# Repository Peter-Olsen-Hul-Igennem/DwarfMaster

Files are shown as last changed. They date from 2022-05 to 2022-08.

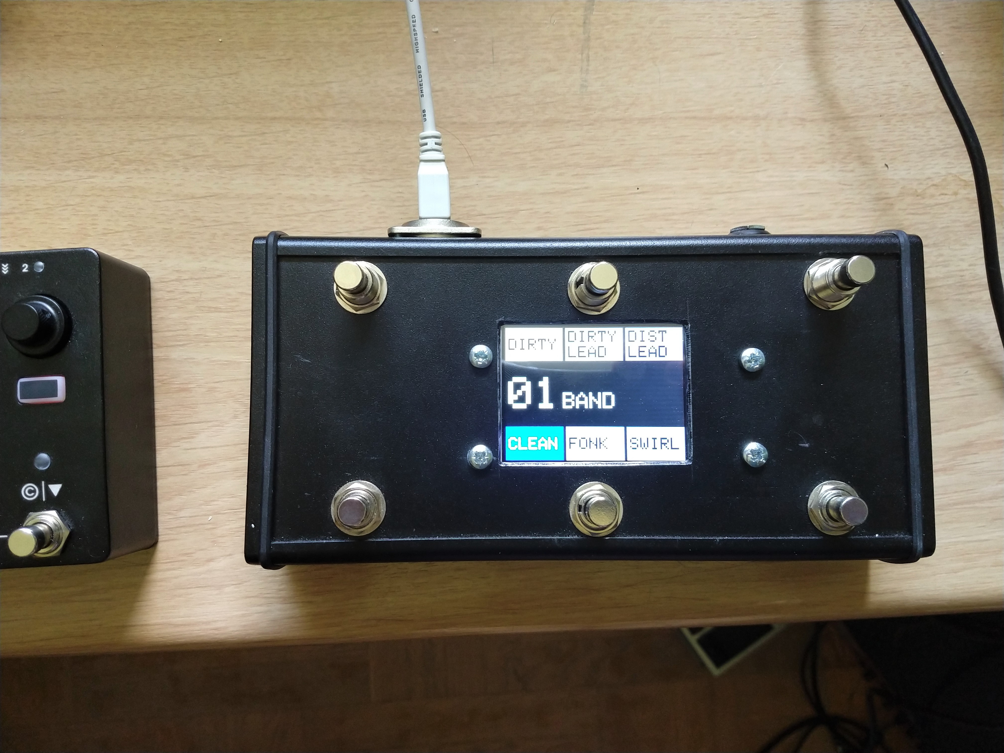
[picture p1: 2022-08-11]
misc/DwarfMaster.jpg

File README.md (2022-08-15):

# DwarfMaster
11-08-2022

Midi controller for Mod Devices Dwarf

As no commercially avalible midi foot controller meet all of my requirements I have decided to build one myself.

The controller is build with a Teensy 4.1 as the "brain". The Teensy is fitted with a MicroSD card for storrage of data.
The controller has a small touch screen that shows selected bank, patch and other relevant info. The "programming" of the controller is also done with the touch screen.

This repository will hold source files and other documentation related to the build.
This is not ment to be a community project as the controller is tailored to my specific needs, but all code is avalible to anyone doing a similar project.
This is my first project using the Arduino/Teensy platform, and the code shows that I'm learning as I go - so quite a few "hacks" and inconsistencies can be found.

The code is developed using VisualTeensy and Visual Studio Code.
These libraries are used: ArduinoJson 6.19.4, Adafruit_BusIO 1.11.5, Adafruit_TouchScreen 1.1.3, Adafruit_GFX_Library 1.10.14, MCUFRIEND_kbv 2.9.9, EEPROM 2.0, SD 2.0.0, SdFat 2.1.0, SPI 1.0, Wire 1.0, MIDI Library 5.0.2

The controller has 6 footswitches that can be set up as a "preset" of "toggle" button. The preset footswitches are mutually exclusive. Pressing a footswitch can trigger up to 16 PC and 16 CC messages being send. Preset footswitches can be configured to have a secondary press function that can send another 16 PC and 16 CC massages.

The six footswitches constitute a Bank. There are 100 banks. A PC message can be send on changing to a new bank (to load a pedalboard in the Dwarf). Bank up and down is done with pressing footswitch 1+2 (down) and 2+3 (up).

All configuration of footswitches and banks (names, pc's, cc's, preset/toggle, 2. function) is done via the touchscreen with footswitch 3 as "ok" button and footswitch 1 as "cancel/exit".
There is utility functions for copying banks and footswitches as well as sending a single CC (for midi-learn purpose).

All midi messages are send on both the USB port as well as a standard 5 pin midi connector.

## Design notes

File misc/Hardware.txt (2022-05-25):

Teensy 4.1	: https://www.conradelektronik.dk/p/pjrc-mikrocontroller-teensy-41-2269230
Display		: https://www.conradelektronik.dk/p/tru-components-touchscreen-monitor-71-cm-28-tommer-320-x-240-pixel-inkl-touchpen-2144984
Buttons		: https://www.banzaimusic.com/Momentary-Soft-Touch-SPST-NO-Long.html

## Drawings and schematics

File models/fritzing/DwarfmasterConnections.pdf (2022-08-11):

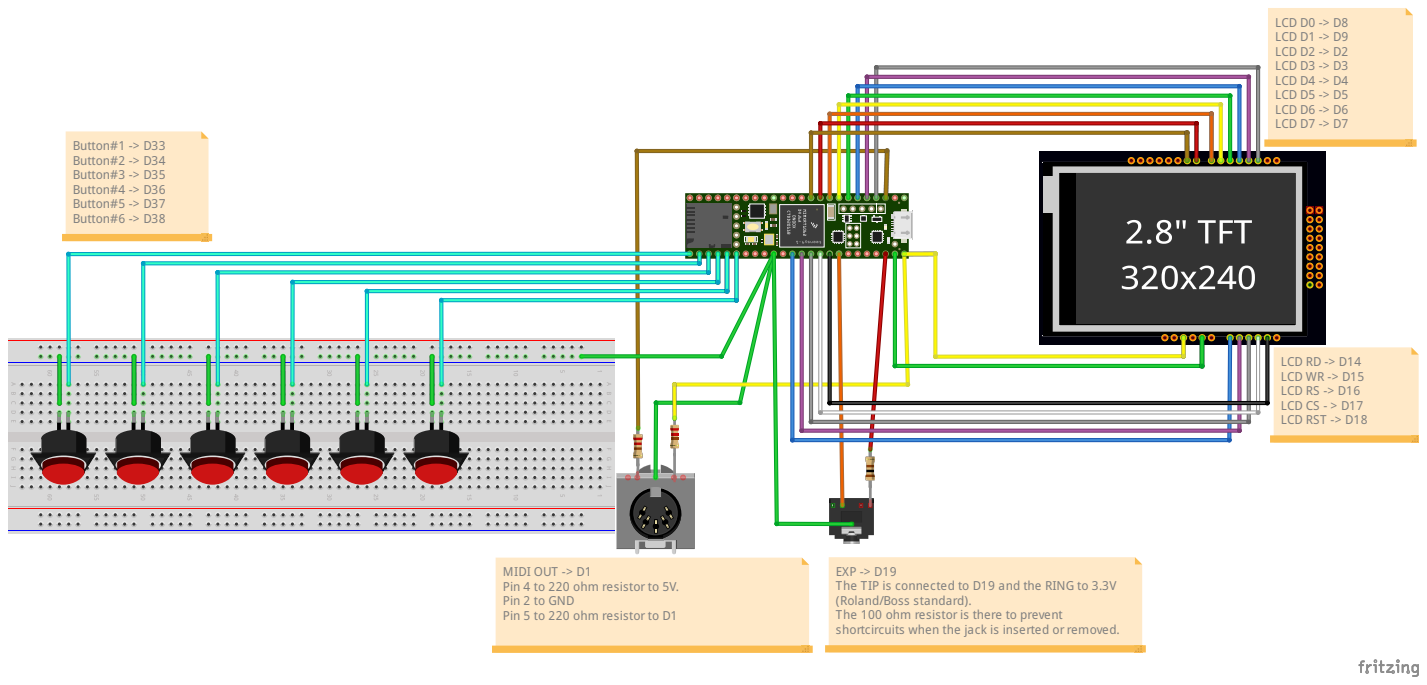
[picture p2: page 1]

MIDI OUT -> D1
Pin 4 to 220 ohm resistorto 5V.
Pin 2 to GND
Pin 5 to 220 ohm resistorto D1

EXP -> D19
The TIP is connected to D19 and the RING to 3.3V
(Roland/Boss standard).
The 100 ohm resistoris there to prevent
shortcircuits when the jack is inserted orremoved.

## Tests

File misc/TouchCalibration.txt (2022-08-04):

I'm using the MCUFREIND_kbv library to read touch data from the screen. Every touch screen is different so some screen specific values needs to be set up.
The values are meassured/retreived with the TouchScreen_Calibr_native.ino sketch that comes with MCUFREIND_kbv

I needed to make a small change in the sketch so the touch was read on the correct pins (found with the diagnose_Touchpins sketch):
int XP=8, XM=A2, YP=A3, YM=9;

These are the values for my screen:

const int TS_LEFT=937,TS_RT=99,TS_TOP=72,TS_BOT=915;

PORTRAIT CALIBRATION     240 x 320
x = map(p.x, LEFT=937, RT=99, 0, 240)
y = map(p.y, TOP=72, BOT=915, 0, 320)

LANDSCAPE CALIBRATION    320 x 240
x = map(p.y, LEFT=72, RT=915, 0, 320)
y = map(p.x, TOP=99, BOT=937, 0, 240)

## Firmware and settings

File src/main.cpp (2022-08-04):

#include "ButtonState.h"
#include "ExpressionHandler.h"
#include "GlobalConst.h"
#include "MidiCtrlData.h"
#include "MidiTransmitter.h"
#include "Screen.h"
#include "Touch.h"
#include <Arduino.h>
#include <EEPROM.h>

enum CtrlState { PLAY,
                 PLAY_BANK_UP,
                 PLAY_BANK_DOWN,
                 EDIT_BANK,
                 EDIT_BTN };
CtrlState ctrlState = PLAY;

enum BtnPushState { VERY_FIRST_BTN_PUSH,
                    FIRST_BTN_PUSH,
                    SECOND_BTN_PUSH };

enum PcCcEnum { PC_1_8,
                PC_9_16,
                CC_1_8,
                CC_9_16 };

const uint16_t DATA_STATE_EEPROM_ADR = 0;
const uint8_t EXP_PIN                = 19;

void setup();
void loop();

void playMode();
void bankChange(bool up);
void drawPlayScreen();
void drawPlayBtns(const bool overrideSelected, const bool invertSelected = false);
void drawPlayBank(const int bnkNbr, const bool inverted);
void sendButtonMidi(Button button, BtnPushState btnState);

void editMode(uint8_t editBtnNbr);
void doEditUtility();
bool doEditBank();
bool doEditBtn(uint8_t btnNbr);
bool doPcCcEdit(Button* button, uint8_t btnNbr, PcCcEnum pcCc);
bool doPcCcDetailsEdit(Button* button, uint8_t btnNbr, uint8_t pcCcNbr, PcCcEnum pcCc);

void loadDataStateInfo();
void saveDataStateInfo();
void bankNumToChar(uint8_t num, char* buf);
void initHousekeepingVariables();
void togglePushBtnState(uint8_t btnNbr);

void setMainLabelAttributes();
void setUtilityLabelAttributes();
void setBankLabelAttributes();
void setButtonLabelAttributes(const Button* button);
void setPc1LabelAttributes(const Button* button);
void setPc2LabelAttributes(const Button* button);
void setCc1LabelAttributes(const Button* button);
void setCc2LabelAttributes(const Button* button);
void setPcDetailLabelAttributes(const PcMsg* msg);
void setCcDetailLabelAttributes(const CcMsg* msg);

EditLabelAttributes editLabelAttrib[9];

Screen screen; // TODO pointer
MidiCtrlData* mcd;
Bank* bank;
ButtonState* btnState = btnState->getInstance();
MidiTransmitter* midiTransmitter;
ExpressionHandler* expressionHandler;

struct DataState
{
    uint8_t bnk;
    uint8_t btn;
    BtnPushState btnPushState = VERY_FIRST_BTN_PUSH;
    uint16_t expMin;
    uint16_t expMax;
};
DataState dataState;

bool toggleStates[NUMBER_OF_BUTTONS]; // Keeping track of the states of the toggle switches (buttons not set up to be patches). True is ON.

void setup()
{
    Serial.begin(9600);
    //    delay(1000);

    loadDataStateInfo();
    mcd  = new MidiCtrlData();
    bank = mcd->getBank(dataState.bnk);

    expressionHandler = new ExpressionHandler(EXP_PIN, dataState.expMin, dataState.expMax);
    midiTransmitter   = new MidiTransmitter(expressionHandler);

    initHousekeepingVariables();

    screen.showWaitScreen();
    screen.waitForButtonReleased();

    sendButtonMidi(bank->buttons[dataState.btn - 1], dataState.btnPushState);

    drawPlayScreen();
}

void loop()
{
    uint8_t playBtnPressed = 0;

    // switch that sets up state
    switch (ctrlState)
    {
        case PLAY:
            if (btnState->isBankUpState())
            {
                ctrlState = PLAY_BANK_UP;
            }
            else if (btnState->isBankDownState())
            {
                ctrlState = PLAY_BANK_DOWN;
            }
            else if (screen.playBankPressed())
            {
                ctrlState = EDIT_BANK;
            }
            else
            {
                playBtnPressed = screen.playBtnPressed();
                if (playBtnPressed > 0)
                {
                    ctrlState = EDIT_BTN;
                }
            }

            break;

        case PLAY_BANK_UP:
        case PLAY_BANK_DOWN:
            ctrlState = PLAY;
            break;

        case EDIT_BANK:
        case EDIT_BTN:
            ctrlState = PLAY;
            break;
    }

    // switch that reacts to a given state
    switch (ctrlState)
    {
        case PLAY:
            playMode();
            break;
        case PLAY_BANK_UP:
            bankChange(true);
            break;
        case PLAY_BANK_DOWN:
            bankChange(false);
            break;
        case EDIT_BANK:
            editMode(0);
            break;
        case EDIT_BTN:
            editMode(playBtnPressed);
            break;
    }

    while (usbMIDI.read())
    {
        // ignore incoming messages
    }
}

void playMode()
{
    byte btnNbr = btnState->getSingleButtonPressed();
    if (btnNbr > 0) // A footswitch was pushed
    {
        if (bank->buttons[btnNbr - 1].isPatch)
        {
            if (btnNbr == dataState.btn)
                togglePushBtnState(btnNbr - 1);
            else
                dataState.btnPushState = VERY_FIRST_BTN_PUSH;
            
            sendButtonMidi(bank->buttons[btnNbr - 1], dataState.btnPushState);
            dataState.btn = btnNbr;
            saveDataStateInfo();
        }
        else
        {
            toggleStates[btnNbr - 1] = !toggleStates[btnNbr - 1];
            if (toggleStates[btnNbr - 1])
                sendButtonMidi(bank->buttons[btnNbr - 1], FIRST_BTN_PUSH);
            else
                sendButtonMidi(bank->buttons[btnNbr - 1], SECOND_BTN_PUSH);
        }

        drawPlayBtns(false);
    }
    else
    {
        for (uint8_t i = 0; i < NUMBER_OF_BUTTONS; i++)
        {
            if (!bank->buttons[i].isLatching && btnState->isButtonJustReleased(i + 1))
            {
                if (bank->buttons[i].isPatch)
                    togglePushBtnState(i);
                else
                    toggleStates[i] = !toggleStates[i];
                
                sendButtonMidi(bank->buttons[i], SECOND_BTN_PUSH);
                drawPlayBtns(false);
            }
        }
    }

    // Send Expressionpedal midi
    midiTransmitter->sendExpressionMessages(bank, toggleStates, dataState.btn);
}

void bankChange(bool up)
{
    unsigned long prevMillis = millis();
    unsigned long curMillis;
    const unsigned long period = 500;
    int btnNbr1;
    int btnNbr2;
    bool bBlink     = false;
    bool first      = true;
    byte tmpBankNbr = dataState.bnk;

    while (true)
    {
        if ((first && up) || btnState->isBankUpState())
        {
            if (tmpBankNbr == NUMBER_OF_BANKS - 1)
                tmpBankNbr = 0;
            else
                tmpBankNbr++;
            bank = mcd->getBank(tmpBankNbr);
        }
        else if ((first && !up) || btnState->isBankDownState())
        {
            if (tmpBankNbr == 0)
                tmpBankNbr = NUMBER_OF_BANKS - 1;
            else
                tmpBankNbr--;
            bank = mcd->getBank(tmpBankNbr);
        }
        first = false;

        curMillis = millis();
        if (curMillis - prevMillis >= period)
        {
            bBlink = !bBlink;
            drawPlayBank(tmpBankNbr, bBlink);
            drawPlayBtns(true);
            prevMillis = curMillis;
        }
        btnNbr1 = btnState->getSingleButtonPressed();
        if (btnNbr1 > 0 && bank->buttons[btnNbr1 - 1].isPatch) // Load selected bank
        {
            midiTransmitter->sendPcMsg(bank->pcMessage, true); // Send Bank Midi

            dataState.bnk          = tmpBankNbr;
            dataState.btn          = btnNbr1;
            dataState.btnPushState = VERY_FIRST_BTN_PUSH;
            saveDataStateInfo();
            initHousekeepingVariables();

            bBlink = true;
            while (true)
            {
                btnNbr2 = btnState->getSingleButtonPressed(true);
                if (btnNbr1 == btnNbr2) // The seledted button (patch) is pressed again.
                {                       // This allows the user to wait until the bank is loaded in the Dwarf, before sending patch related midi messages.
                    break;
                }
                curMillis = millis();
                if (curMillis - prevMillis >= period)
                {
                    bBlink = !bBlink;
                    drawPlayBtns(false, bBlink);
                    prevMillis = curMillis;
                }
                if (usbMIDI.read()) // Recieving any midi data from the Dwarf will signal that the bank is loaded. Tip: The InfamousMindi will send a midi msg on loading! 
                    break;
            }

            sendButtonMidi(bank->buttons[btnNbr1 - 1], dataState.btnPushState);

            drawPlayScreen();

            break;
        }
    }
}

void drawPlayScreen()
{
    screen.blankScreen();
    drawPlayBtns(false);
    drawPlayBank(dataState.bnk, false);
}

void drawPlayBtns(const bool overrideSelected, const bool invertSelected)
{
    byte curPatch    = dataState.btn;
    bool selected    = false;
    bool primaryFunc = true;

    for (byte i = 0; i < NUMBER_OF_BUTTONS; i++)
    {
        primaryFunc = true;
        if (!overrideSelected)
            selected = curPatch == i + 1; // Blue color patch
        if (bank->buttons[i].isPatch)
        {
            if (selected && dataState.btnPushState == SECOND_BTN_PUSH)
                primaryFunc = false; // Red color patch
        }
        else
        {
            if (toggleStates[i] == true)
                primaryFunc = false; // Toggle ON
        }
        screen.drawPlayButton(i + 1, bank->buttons[i].isPatch, selected, primaryFunc, bank->buttons[i].name, invertSelected);
    }
}

void drawPlayBank(const int bnkNbr, const bool inverted)
{
    char bankNumber[3];
    bankNumToChar(bnkNbr, bankNumber);
    screen.drawPlayBank(bankNumber, bank->name, inverted);
}

void sendButtonMidi(Button button, BtnPushState btnState)
{
    for (uint8_t i = 0; i < NUMBER_OF_MIDI_MSG; i++)
    {
        switch (btnState)
        {
            case VERY_FIRST_BTN_PUSH:
                midiTransmitter->sendPcMsg(button.pcMessages[i], true);
                break;

            case FIRST_BTN_PUSH:
                if (button.pcMessages[i].valueOn != button.pcMessages[i].valueOff) // If the On and Off values are the same, the PC is not (re)sent.
                    midiTransmitter->sendPcMsg(button.pcMessages[i], true);
                break;

            case SECOND_BTN_PUSH:
                if (!button.isPatch || button.isSecondPushEnabled)                     // Toggle or secondPushEnabled
                    if (button.pcMessages[i].valueOn != button.pcMessages[i].valueOff) // If the On and Off values are the same, the PC is not (re)sent.
                        midiTransmitter->sendPcMsg(button.pcMessages[i], false);
                break;
        }
    }

    for (uint8_t i = 0; i < NUMBER_OF_MIDI_MSG; i++)
    {
        switch (btnState)
        {
            case VERY_FIRST_BTN_PUSH:
            case FIRST_BTN_PUSH:
                midiTransmitter->sendCcMsg(button.ccMessages[i], true, button.ccMessages[i].useMaxValAsCcNbr);
                break;

            case SECOND_BTN_PUSH:
                if (!button.isPatch || button.isSecondPushEnabled)
                {
                    midiTransmitter->sendCcMsg(button.ccMessages[i], false, button.ccMessages[i].useMaxValAsCcNbr);
                }
                break;
        }
    }
}


/*
 * EDIT functions starts here
 */
void editMode(uint8_t editBtnNbr)
{
    bool dirty = false;
    char label[13];
    bankNumToChar(dataState.bnk, label);
    label[2] = ' ';

    int btn;
    bool loop = true;

    if (editBtnNbr > 0) // A field representing a button on the screen was pressed
    {
        loop  = false;
        dirty = doEditBtn(editBtnNbr);
    }

    while (loop)
    {
        strlcpy(label + 3, bank->name, 13);
        setMainLabelAttributes();
        screen.drawEdit(label, editLabelAttrib);
        screen.waitForButtonReleased();

        btn = screen.getButtonPushed();
        switch (btn)
        {
            case 0: // CALCEL
            case 1: // EXIT
                loop = false;
                break;
            case 2: // BANK
                dirty = doEditBank() || dirty;
                break;
            case 3: // UTILITY
                doEditUtility();
                break;
            case 4: // BTN #4
            case 5: // BTN #5
            case 6: // BTN #6
            {
                dirty = doEditBtn(btn) || dirty;
                break;
            }
            case 7: // BTN #1
            case 8: // BTN #2
            case 9: // BTN #3
            {
                dirty = doEditBtn(btn - 6) || dirty;
                break;
            }
        }
    }

    if (dirty)
        mcd->saveBank(dataState.bnk);

    drawPlayScreen();
    screen.waitForButtonReleased();
}

void doEditUtility()
{
    int btn;
    bool loop = true;

    char label1[16];
    char label2[16];
    char cNewVal[4];
    String label;
    String sVal;
    uint16_t newVal;

    while (loop)
    {
        setUtilityLabelAttributes();
        screen.drawEdit("UTILITY", editLabelAttrib);
        screen.waitForButtonReleased();

        btn = screen.getButtonPushed();
        switch (btn)
        {
            case 0: // CALCEL
            case 1: // EXIT
                loop = false;
                break;
            case 2: // COPY BANK
            {
                label          = String("TO BANK");
                sVal           = String(dataState.btn);
                uint8_t bankTo = screen.getNumKeyboardInputFromUser(&label, &sVal, 2);
                if (bankTo > NUMBER_OF_BANKS)
                {
                    screen.showMessage("INVALID CHOICE");
                    break;
                }

                strlcpy(label2, "   CANCEL ", sizeof(label2));
                strlcpy(label1, "BANK: ", sizeof(label1));
                itoa(dataState.bnk, cNewVal, 10);
                strlcat(label1, cNewVal, sizeof(label1));
                strlcat(label1, "->", sizeof(label1));
                itoa(bankTo, cNewVal, 10);
                strlcat(label1, cNewVal, sizeof(label1));
                if (screen.getBinaryInputFromUser(label1, label2, false))
                {
                    mcd->copyBank(dataState.bnk, bankTo);
                }
                break;
            }

            case 3: // RESET BANK
            {
                strcpy(label1, " RESET BANK");
                strcpy(label2, "   CANCEL");
                if (screen.getBinaryInputFromUser(label1, label2, false))
                {
                    mcd->resetBank(dataState.bnk);
                }
                break;
            }
            case 4: // EXP CALIBRATION
            {
                screen.showMessage("MOVE PEDAL TO THE <MIN> POSITION AND PRESS THE SCREEN");
                dataState.expMin = expressionHandler->readCalibrationValue(false);
                screen.showMessage("MOVE PEDAL TO THE <MAX> POSITION AND PRESS THE SCREEN");
                dataState.expMax = expressionHandler->readCalibrationValue(true);

                char msg[85];
                char val[5];
                strlcpy(msg, "MIN: ", 85);
                itoa(dataState.expMin, val, 10);
                strlcpy(msg + strlen(msg), val, 85);
                strlcpy(msg + strlen(msg), "         MAX: ", 85);
                itoa(dataState.expMax, val, 10);
                strlcpy(msg + strlen(msg), val, 85);
                screen.showMessage(msg);

                saveDataStateInfo();
                break;
            }
            case 5: // COPY BUTTON
            {
                label           = String("BTN FROM");
                sVal            = String(dataState.btn);
                uint8_t btnFrom = screen.getNumKeyboardInputFromUser(&label, &sVal, 1);
                if (btnFrom == 0)
                {
                    screen.showMessage("NO BUTTON CHOSEN");
                    break;
                }
                else if (btnFrom > NUMBER_OF_BUTTONS)
                {
                    screen.showMessage("INVALID CHOICE");
                    break;
                }

                label          = String("TO BANK");
                sVal           = String(dataState.bnk);
                uint8_t bankTo = screen.getNumKeyboardInputFromUser(&label, &sVal, 2);
                // No need to check if bankTo > 99, because getNumKeyboardInputFromUser(&label, &sVal, 2) only allows 2 digits

                label         = String("TO BUTTON");
                sVal          = String(dataState.btn);
                uint8_t btnTo = screen.getNumKeyboardInputFromUser(&label, &sVal, 1);
                if (btnTo == 0)
                {
                    screen.showMessage("NO BUTTON CHOSEN");
                    break;
                }
                else if (btnTo > NUMBER_OF_BUTTONS)
                {
                    screen.showMessage("INVALID CHOICE");
                    break;
                }

                strlcpy(label2, "   CANCEL ", sizeof(label2));
                strlcpy(label1, "BTN:", sizeof(label1));
                itoa(btnFrom, cNewVal, 10);
                strlcat(label1, cNewVal, sizeof(label1));
                strlcat(label1, " > ", sizeof(label1));
                itoa(bankTo, cNewVal, 10);
                strlcat(label1, cNewVal, sizeof(label1));
                strlcat(label1, " ", sizeof(label1));
                itoa(btnTo, cNewVal, 10);
                strlcat(label1, cNewVal, sizeof(label1));
                if (screen.getBinaryInputFromUser(label1, label2, false))
                {
                    mcd->copyButton(dataState.bnk, btnFrom - 1, bankTo, btnTo - 1);
                }
                break;
            }
            case 6: // RESET BUTTON
            {
                label  = String("BTN NBR");
                sVal   = String("0");
                newVal = screen.getNumKeyboardInputFromUser(&label, &sVal, 1);
                if (newVal == 0)
                {
                    screen.showMessage("NO BUTTON CHOSEN");
                    break;
                }
                else if (newVal > NUMBER_OF_BUTTONS)
                {
                    screen.showMessage("INVALID CHOICE");
                    break;
                }

                strlcpy(label2, "   CANCEL", sizeof(label2));
                itoa(newVal, cNewVal, 10);
                strlcpy(label1, "RESET BTN: ", sizeof(label1));
                strlcat(label1, cNewVal, sizeof(label1));
                if (screen.getBinaryInputFromUser(label1, label2, false))
                {
                    mcd->resetButton(dataState.bnk, newVal - 1);
                }
                break;
            }
            case 7: {
                label      = String("CHANNEL");
                sVal       = String("1");
                uint8_t ch = screen.getNumKeyboardInputFromUser(&label, &sVal, 2);
                if (ch == 0)
                {
                    screen.showMessage("NO CHANNEL CHOSEN");
                    break;
                }
                else if (ch > 16)
                {
                    screen.showMessage("INVALID CHOICE");
                    break;
                }

                label       = String("CC NBR");
                sVal        = String("0");
                uint16_t cc = screen.getNumKeyboardInputFromUser(&label, &sVal, 3);
                if (cc > 127)
                {
                    screen.showMessage("INVALID CHOICE");
                    break;
                }

                strlcpy(label2, "   CANCEL", sizeof(label2));
                strlcpy(label1, "CH:", sizeof(label1));
                itoa(ch, cNewVal, 10);
                strlcat(label1, cNewVal, sizeof(label1));
                strlcat(label1, " CC:", sizeof(label1));
                itoa(cc, cNewVal, 10);
                strlcat(label1, cNewVal, sizeof(label1));
                if (screen.getBinaryInputFromUser(label1, label2, false))
                {
                    usbMIDI.sendControlChange(cc, 127, ch);
                }
                break;
            }
            case 8:
            case 9:
                break;
        }
    }
}
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

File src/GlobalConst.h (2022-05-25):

#ifndef DWARFMASTER_GLOBAL_CONST_H
#define DWARFMASTER_GLOBAL_CONST_H

#include <arduino.h>

static const uint16_t DISPLAY_WIDTH = 320;
static const uint16_t DISPLAY_HEIGHT = 240;
static const uint16_t BACKGROUND_COLOR = 0xC618; //TFT_LIGHTGREY;
static const uint16_t LINE_COLOR = 0x7BEF; //TFT_DARKGREY;

static const uint8_t NUMBER_OF_BANKS = 100;
static const uint8_t NUMBER_OF_BUTTONS = 6;
static const uint8_t NUMBER_OF_MIDI_MSG = 16;
static const uint8_t BANK_NAME_LENGTH = 9;
static const uint8_t BUTTON_NAME_LENGTH = 10;

#endif

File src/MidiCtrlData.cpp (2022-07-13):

#include "MidiCtrlData.h"
#include <EEPROM.h>
#include <SD.h>
#include <SPI.h>

MidiCtrlData::MidiCtrlData()
{
    folder = strdup(PREFIX_VER);
    strcat(folder, MIDI_CTRL_DATA_VERSION);

    if (verifyVersionFolderExists())
    {
        Serial.print("Version folder OK: ");
        Serial.println(folder); 
        deserialize();
    }
    else
    {
        Serial.print("Version folder ERR: ");
        Serial.println(folder);
        initialize();
        serialize();
    }  
/*
    for (int i = 0; i < 100; i++)
    {
        for (size_t j = 0; j < 6; j++)
        {
            banks[i].buttons[j].isLatching = true;
        }
    }
    serialize();
*/
}

Bank* MidiCtrlData::getBank(uint8_t bankNbr)
{
    return &banks[bankNbr];
}

void MidiCtrlData::saveBank(const uint8_t bankNbr)
{
    serializeBank(bankNbr);
}

void MidiCtrlData::resetBank(const uint8_t bankNbr)
{
    initializeBank(bankNbr);
    serializeBank(bankNbr);
}

void MidiCtrlData::copyBank(const uint8_t bankNbrFrom, const uint8_t bankNbrTo)
{
    strcpy(banks[bankNbrTo].name, banks[bankNbrFrom].name);
    banks[bankNbrTo].pcMessage.channel  = banks[bankNbrFrom].pcMessage.channel;
    banks[bankNbrTo].pcMessage.valueOn  = banks[bankNbrFrom].pcMessage.valueOn;
    banks[bankNbrTo].pcMessage.valueOff = banks[bankNbrFrom].pcMessage.valueOff;
    for (int j = 0; j < NUMBER_OF_BUTTONS; j++)
    {
        copyButtonData(bankNbrFrom, j, bankNbrTo, j);
    }

    serializeBank(bankNbrTo);
}

void MidiCtrlData::resetButton(const uint8_t bankNbr, const uint8_t buttonNbr)
{
    initializeButton(bankNbr, buttonNbr);
    serializeBank(bankNbr);
}

void MidiCtrlData::copyButton(const uint8_t bankNbrFrom, const uint8_t buttonNbrFrom, const uint8_t bankNbrTo, const uint8_t buttonNbrTo)
{
    copyButtonData(bankNbrFrom, buttonNbrFrom, bankNbrTo, buttonNbrTo);
    serializeBank(bankNbrTo);
}

void MidiCtrlData::copyButtonData(const uint8_t bankNbrFrom, const uint8_t buttonNbrFrom, const uint8_t bankNbrTo, const uint8_t buttonNbrTo)
{
    strcpy(banks[bankNbrTo].buttons[buttonNbrTo].name, banks[bankNbrFrom].buttons[buttonNbrFrom].name);
    banks[bankNbrTo].buttons[buttonNbrTo].isPatch                = banks[bankNbrFrom].buttons[buttonNbrFrom].isPatch;
    banks[bankNbrTo].buttons[buttonNbrTo].isSecondPushEnabled    = banks[bankNbrFrom].buttons[buttonNbrFrom].isSecondPushEnabled;
    banks[bankNbrTo].buttons[buttonNbrTo].isInitialToggleStateOn = banks[bankNbrFrom].buttons[buttonNbrFrom].isInitialToggleStateOn;
    banks[bankNbrTo].buttons[buttonNbrTo].isLatching             = banks[bankNbrFrom].buttons[buttonNbrFrom].isLatching;
    for (int k = 0; k < NUMBER_OF_MIDI_MSG; k++)
    {
        banks[bankNbrTo].buttons[buttonNbrTo].pcMessages[k].channel          = banks[bankNbrFrom].buttons[buttonNbrFrom].pcMessages[k].channel;
        banks[bankNbrTo].buttons[buttonNbrTo].pcMessages[k].valueOn          = banks[bankNbrFrom].buttons[buttonNbrFrom].pcMessages[k].valueOn;
        banks[bankNbrTo].buttons[buttonNbrTo].pcMessages[k].valueOff         = banks[bankNbrFrom].buttons[buttonNbrFrom].pcMessages[k].valueOff;
        banks[bankNbrTo].buttons[buttonNbrTo].ccMessages[k].channel          = banks[bankNbrFrom].buttons[buttonNbrFrom].ccMessages[k].channel;
        banks[bankNbrTo].buttons[buttonNbrTo].ccMessages[k].ccNumber         = banks[bankNbrFrom].buttons[buttonNbrFrom].ccMessages[k].ccNumber;
        banks[bankNbrTo].buttons[buttonNbrTo].ccMessages[k].minValue         = banks[bankNbrFrom].buttons[buttonNbrFrom].ccMessages[k].minValue;
        banks[bankNbrTo].buttons[buttonNbrTo].ccMessages[k].maxValue         = banks[bankNbrFrom].buttons[buttonNbrFrom].ccMessages[k].maxValue;
        banks[bankNbrTo].buttons[buttonNbrTo].ccMessages[k].useMaxValAsCcNbr = banks[bankNbrFrom].buttons[buttonNbrFrom].ccMessages[k].useMaxValAsCcNbr;
        banks[bankNbrTo].buttons[buttonNbrTo].ccMessages[k].ctrlByExp        = banks[bankNbrFrom].buttons[buttonNbrFrom].ccMessages[k].ctrlByExp;
    }
}

void MidiCtrlData::initialize()
{
    for (int i = 0; i < NUMBER_OF_BANKS; i++)
    {
        initializeBank(i);
    }
}

void MidiCtrlData::initializeBank(const uint8_t bankNbr)
{

    strcpy(banks[bankNbr].name, BANK);
    banks[bankNbr].pcMessage.channel  = 0;
    banks[bankNbr].pcMessage.valueOn  = 0;
    banks[bankNbr].pcMessage.valueOff = 0;
    for (int j = 0; j < NUMBER_OF_BUTTONS; j++)
    {
        initializeButton(bankNbr, j);
    }
}

void MidiCtrlData::initializeButton(const uint8_t bankNbr, const uint8_t buttonNbr)
{
    strcpy(banks[bankNbr].buttons[buttonNbr].name, PATCH);
    banks[bankNbr].buttons[buttonNbr].isPatch                = true;
    banks[bankNbr].buttons[buttonNbr].isSecondPushEnabled    = true;
    banks[bankNbr].buttons[buttonNbr].isInitialToggleStateOn = false;
    banks[bankNbr].buttons[buttonNbr].isLatching             = true;
    for (int k = 0; k < NUMBER_OF_MIDI_MSG; k++)
    {
        banks[bankNbr].buttons[buttonNbr].pcMessages[k].channel          = 0;
        banks[bankNbr].buttons[buttonNbr].pcMessages[k].valueOn          = 0;
        banks[bankNbr].buttons[buttonNbr].pcMessages[k].valueOff         = 0;
        banks[bankNbr].buttons[buttonNbr].ccMessages[k].channel          = 0;
        banks[bankNbr].buttons[buttonNbr].ccMessages[k].ccNumber         = 0;
        banks[bankNbr].buttons[buttonNbr].ccMessages[k].minValue         = 0;
        banks[bankNbr].buttons[buttonNbr].ccMessages[k].maxValue         = 0;
        banks[bankNbr].buttons[buttonNbr].ccMessages[k].useMaxValAsCcNbr = false;
        banks[bankNbr].buttons[buttonNbr].ccMessages[k].ctrlByExp        = false;
    }
}

void MidiCtrlData::deserialize()
{
    for (int i = 0; i < NUMBER_OF_BANKS; i++)
    {
        deserializeBank(i);
    }
}
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

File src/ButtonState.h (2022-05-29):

#ifndef DWARFMASTER_BUTTON_STATE_H
#define DWARFMASTER_BUTTON_STATE_H

#include "PushButton.h"
#include <Arduino.h>

class ButtonState
{
 public:
    static ButtonState* getInstance();

    bool isBankDownState();
    bool isBankUpState();
    bool isButtonJustReleased(uint8_t btnNbr);               // Index starts at 1
    uint8_t getSingleButtonPressed(bool resetState = false); // Index starts at 1

 private:
    ButtonState(); // Singleton
    void determineState();
    uint8_t getButtonPressed();

    static ButtonState* instance;
    static const byte NUMBER_OF_PUSHBUTTONS = 6;
    PushButton* buttons[NUMBER_OF_PUSHBUTTONS];
    uint8_t state;
    uint64_t lastTime               = 0;
    const uint8_t STATE_DELAY       = 50;
    const uint8_t FIRST_PIN_NBR     = 33;
    uint8_t bankChangeButtonPressed = 0;
    uint8_t lastSingleButtonPressed = 0;
};

#endif

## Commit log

2022-05-12 Added files from non-git project
    [DwarfmasterConnections.fzz]
2022-05-15 Added two button states.
2022-05-25 Added Hardware list
    [DwarfmasterConnections.fzz]
2022-05-29 Added unlatch button functionality
2022-08-04 Added conventional 5-pin midi
    [DwarfmasterConnections.fzz]
